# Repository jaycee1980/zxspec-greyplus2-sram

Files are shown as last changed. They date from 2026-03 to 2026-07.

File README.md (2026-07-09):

# zxspec-greyplus2-sram
A replacement RAM module for a ZX Spectrum +2 (Grey) machine to replace 8x4164 chips

# What's it for ?
The grey +2 uses 4164 (64Kx1) DRAM as its system memory... there are two banks of it, one as "Contended" RAM, one as "Uncontended" RAM. This is similar in principle to the 4116 (16x1) DRAM and 4532 (32Kx1) DRAM in the original 48K spectrum. These chips can and do fail, and procuring replacements is getting more and more difficult.

For 48K spectrums, there are Lower and Upper RAM Replacement boards utilising modern 5V SRAM as a replacement. I couldn't find an equivalent solution for a grey +2 though.

So here we are! :)
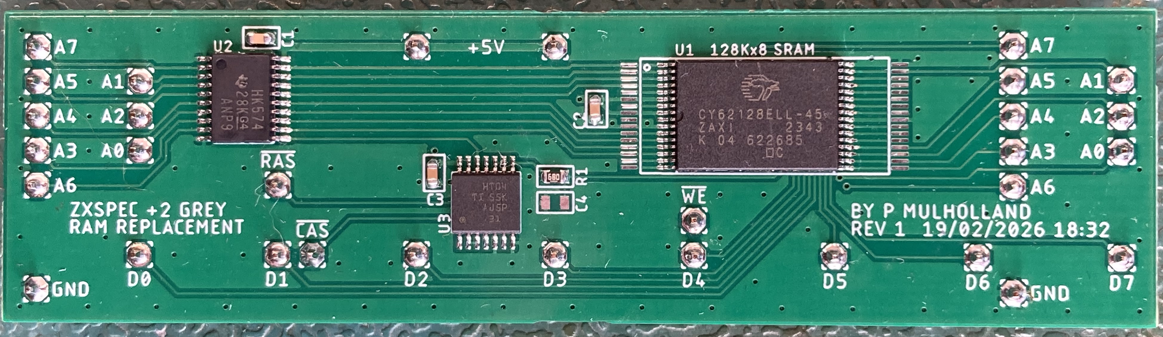
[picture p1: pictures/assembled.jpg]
image of assembled board


# Building it
The gerber.zip file in this repository contains Gerber files needed by a PCB manufacturer to make the board. I personally use [JLCPCB](https://jlcpcb.com) but any PCB manufacturer should be able to produce it.

The [BOM file](/bom.txt) contains the parts needed to make the board. Please note that I have only personally used the Cypress CY62128ELL-45ZAXI memory at the moment, but the other SRAM listed there should also work. You *might* need to install C4 in some cases. My personal grey +2 worked just fine without it.

Also be aware that on the back of the PCB there is a jumper pad. This should be bridged such that the A pad is connected to the middle pad. You can use a solder blob, a short length of wire, or a 0 ohm resistor for this.

# License

If you wish to sell this please contact me at github@dark-matter.me.uk - I will usually grant permission provided they are sold for reasonable cost, and my name is not removed from the design.

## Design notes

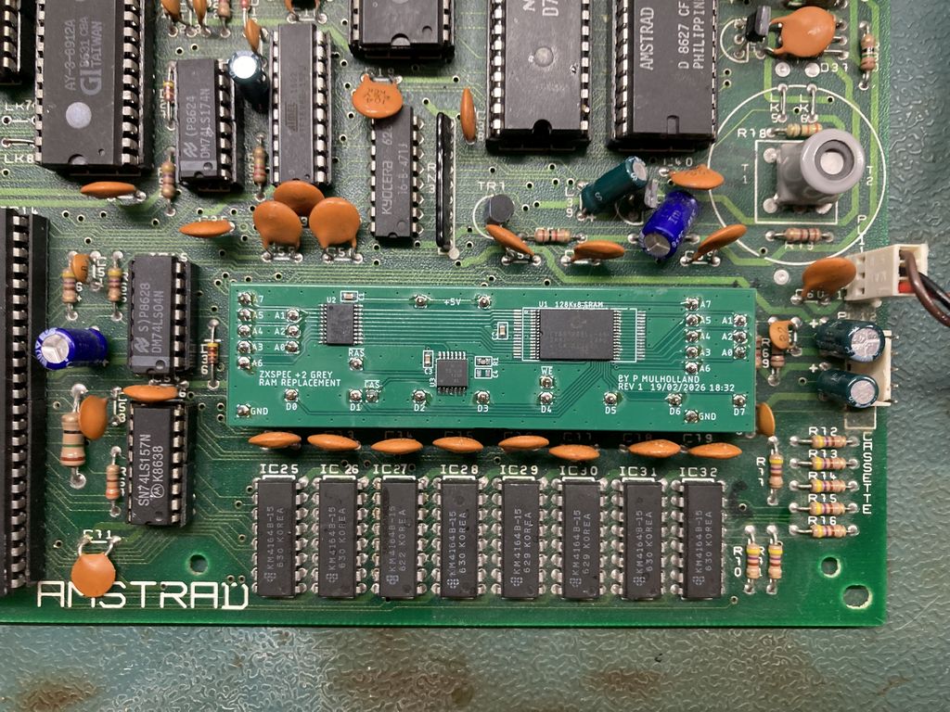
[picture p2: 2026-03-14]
pictures/fitted_th.jpg

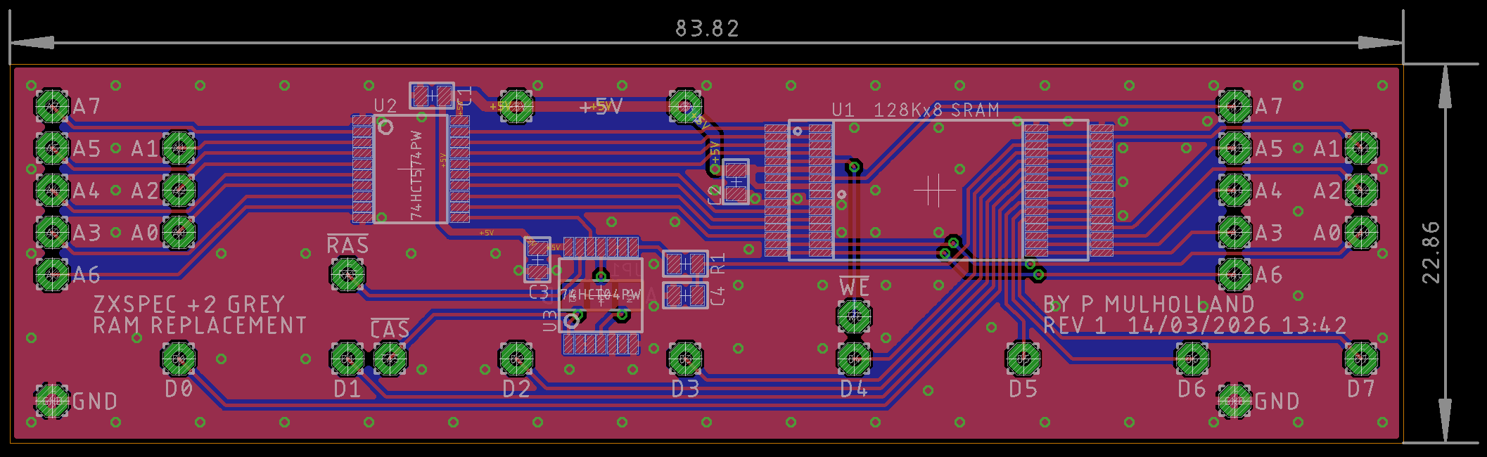
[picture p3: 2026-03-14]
pictures/board.png

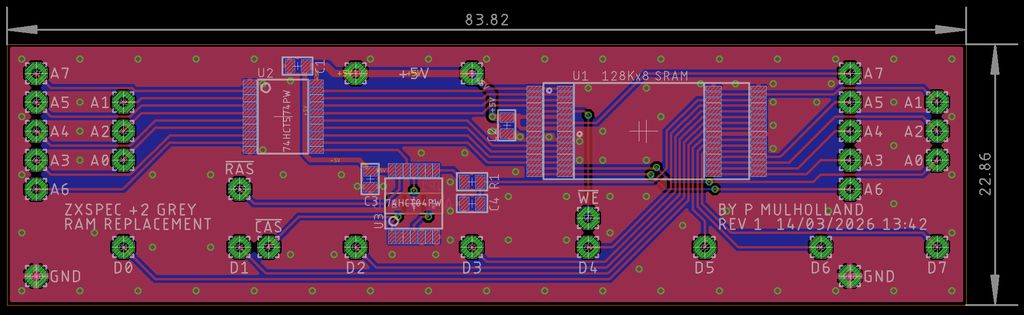
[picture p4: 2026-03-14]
pictures/board_th.jpg

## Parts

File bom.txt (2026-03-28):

Main components:
C1, C3		100nF 50V ceramic capacitor, SMD 0603		Digikey 399-C0603C104K5RACTUCT-ND, Mouser 603-CC0603MR9BB104, LCSC C14663
C2			1uF 16V ceramic capacitor, SMD 0603			Digikey 399-C0603C105K4RACTUCT-ND, Mouser 80-C0603C105K8R, LCSC C15849
R1			68 ohm 1% resistor, SMD 0603				Digikey 311-68.0HRCT-ND, Mouser 603-RC0603FR-1368RL, LCSC C27592
U2			74HCT574, TSSOP 20 package					Digikey 296-17126-1-ND, Mouser 595-CD74HCT574PWR, LCSC C2652839
U3			74HCT04, TSSOP 14 package					Digikey 296-17123-1-ND, Mouser 595-CD74HCT04PWR, LCSC C131695

Optional:
C4			100pF 1% C0G ceramic capacitor, SMD 0603	Digikey 399-C0603C101J5GACTUCT-ND, Mouser 603-CC402FRNPO9BN101, LCSC C14858

Suitable SRAM:
Cypress CY62128ELL-45ZAXI		LCSC C2950636
Infineon CY62128ELL-45ZXI		Digikey 448-CY62128ELL-45ZXITCT-ND, Mouser 727-CY62128ELL45ZXI
ISSI IS62C1024AL-35TLI			Digikey 706-1309-1-ND, Mouser 870IS62C1024AL35TLI
Renesas R1LP0108ESA-5SI#S1		Digikey R1LP0108ESA-5SI#S1CT-ND, Mouser 968-R1LP0108ESA5SIS1
Renesas R1LP0108ESA-5SI#B1		Mouser 968-R1LP0108ESA5SIB1
Alliance AS6C1008-55TIN			Mouser 913-AS6C1008-55TIN

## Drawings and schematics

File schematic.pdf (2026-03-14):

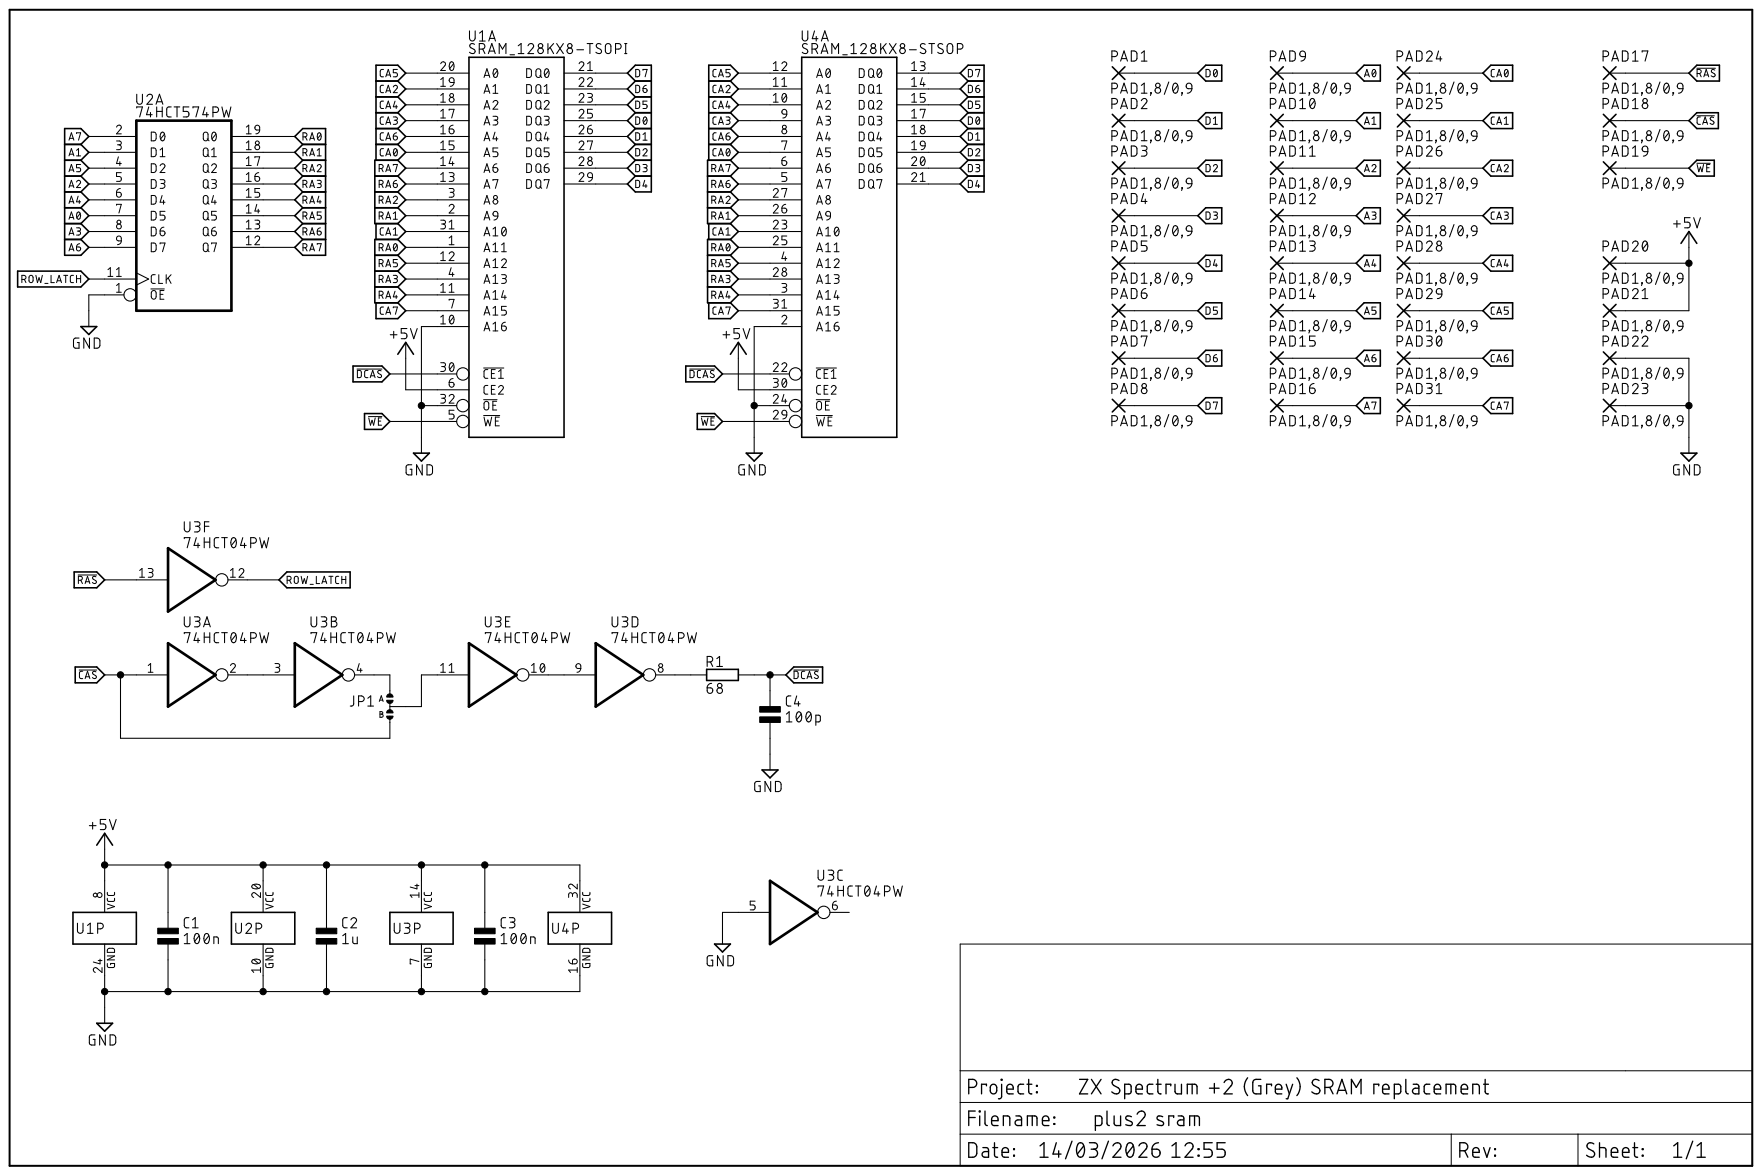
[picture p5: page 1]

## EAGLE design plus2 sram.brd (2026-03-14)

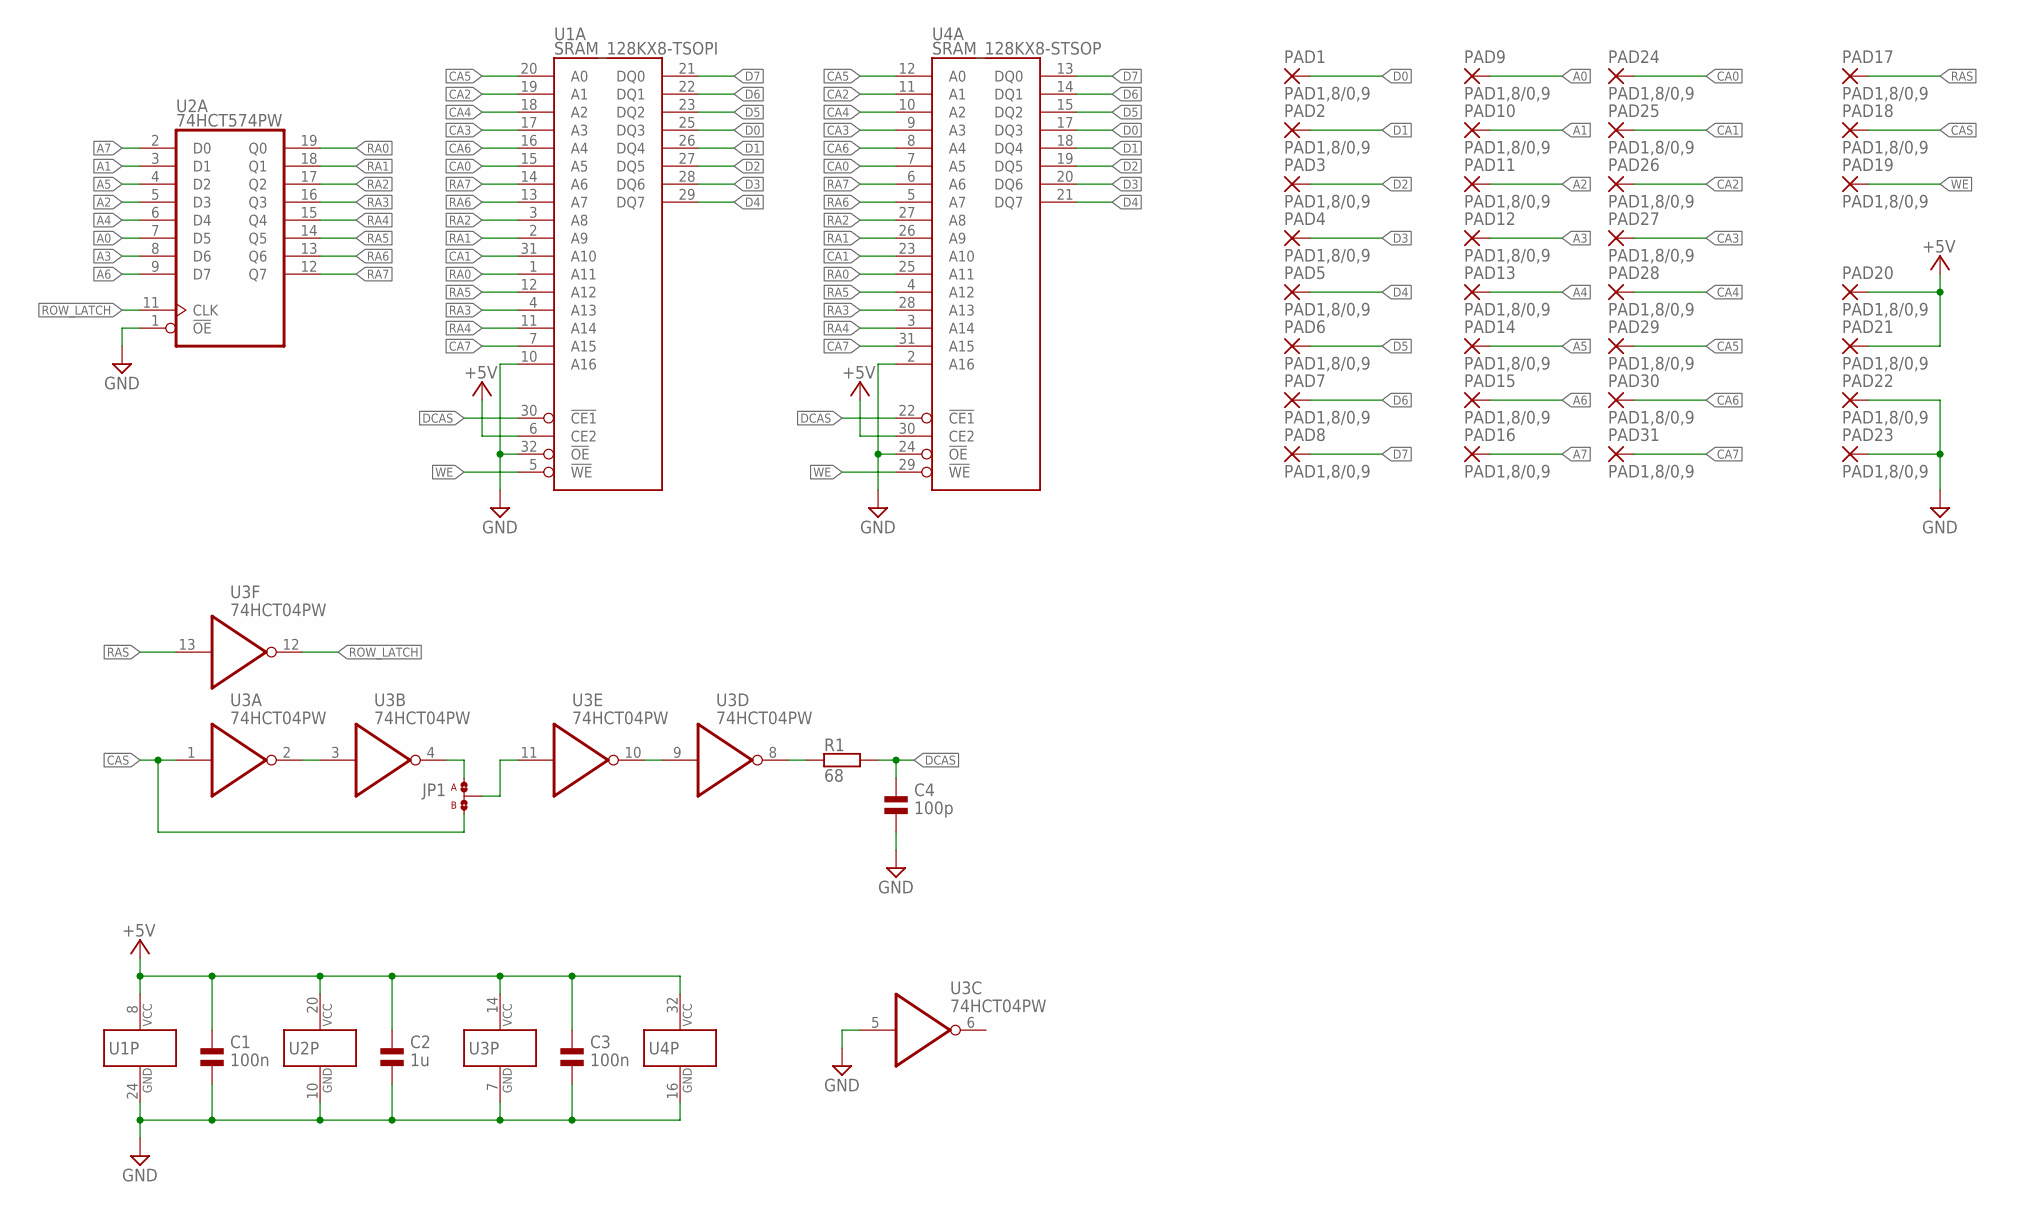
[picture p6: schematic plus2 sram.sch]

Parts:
C1, C3: 100n; 0603
C2: 1u; 0603
C4: 100p; 0603
JP1: JMP-SMD-3W0805; SJ-3P-0805
PAD1, PAD2, PAD3, PAD4, PAD5, PAD6, PAD7, PAD8, PAD9, PAD10, PAD11, PAD12, PAD13, PAD14, PAD15, PAD16, PAD17, PAD18, PAD19, PAD20, PAD21, PAD22, PAD23, PAD24, PAD25, PAD26, PAD27, PAD28, PAD29, PAD30, PAD31: PAD1,8/0,9; 1,8/0,9
R1: 68; 0603
U1: SRAM_128KX8-TSOPI; TSOP-I-32
U2: 74HCT574PW; TSSOP20
U3: 74HCT04PW; TSSOP14
U4: SRAM_128KX8-STSOP; STSOP-32

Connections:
!CAS: JP1.B, PAD18.1, U3.1 (I)
!DCAS: C4.1, R1.2, U1.30 (!CE1), U4.22 (!CE1)
!RAS: PAD17.1, U3.13 (I)
!WE: PAD19.1, U1.5 (!WE), U4.29 (!WE)
+5V: C1.1, C2.1, C3.1, PAD20.1, PAD21.1, U1.6 (CE2), U1.8 (VCC), U2.20 (VCC), U3.14 (VCC), U4.30 (CE2), U4.32 (VCC)
A0: PAD9.1, U2.7 (D5)
A1: PAD10.1, U2.3 (D1)
A2: PAD11.1, U2.5 (D3)
A3: PAD12.1, U2.8 (D6)
A4: PAD13.1, U2.6 (D4)
A5: PAD14.1, U2.4 (D2)
A6: PAD15.1, U2.9 (D7)
A7: PAD16.1, U2.2 (D0)
CA0: PAD24.1, U1.15 (A5), U4.7 (A5)
CA1: PAD25.1, U1.31 (A10), U4.23 (A10)
CA2: PAD26.1, U1.19 (A1), U4.11 (A1)
CA3: PAD27.1, U1.17 (A3), U4.9 (A3)
CA4: PAD28.1, U1.18 (A2), U4.10 (A2)
CA5: PAD29.1, U1.20 (A0), U4.12 (A0)
CA6: PAD30.1, U1.16 (A4), U4.8 (A4)
CA7: PAD31.1, U1.7 (A15), U4.31 (A15)
D0: PAD1.1, U1.25 (DQ3), U4.17 (DQ3)
D1: PAD2.1, U1.26 (DQ4), U4.18 (DQ4)
D2: PAD3.1, U1.27 (DQ5), U4.19 (DQ5)
D3: PAD4.1, U1.28 (DQ6), U4.20 (DQ6)
D4: PAD5.1, U1.29 (DQ7), U4.21 (DQ7)
D5: PAD6.1, U1.23 (DQ2), U4.15 (DQ2)
D6: PAD7.1, U1.22 (DQ1), U4.14 (DQ1)
D7: PAD8.1, U1.21 (DQ0), U4.13 (DQ0)
GND: C1.2, C2.2, C3.2, C4.2, PAD22.1, PAD23.1, U1.10 (A16), U1.24 (GND), U1.32 (!OE), U2.1 (!OE), U2.10 (GND), U3.5 (I), U3.7 (GND), U4.2 (A16), U4.16 (GND), U4.24 (!OE)
unnamed: R1.1, U3.8 (O)
unnamed: U3.2 (O), U3.3 (I)
unnamed: JP1.COM, U3.11 (I)
unnamed: U3.9 (I), U3.10 (O)
unnamed: JP1.A, U3.4 (O)
RA0: U1.1 (A11), U2.19 (Q0), U4.25 (A11)
RA1: U1.2 (A9), U2.18 (Q1), U4.26 (A9)
RA2: U1.3 (A8), U2.17 (Q2), U4.27 (A8)
RA3: U1.4 (A13), U2.16 (Q3), U4.28 (A13)
RA4: U1.11 (A14), U2.15 (Q4), U4.3 (A14)
RA5: U1.12 (A12), U2.14 (Q5), U4.4 (A12)
RA6: U1.13 (A7), U2.13 (Q6), U4.5 (A7)
RA7: U1.14 (A6), U2.12 (Q7), U4.6 (A6)
ROW_LATCH: U2.11 (CLK), U3.12 (O)

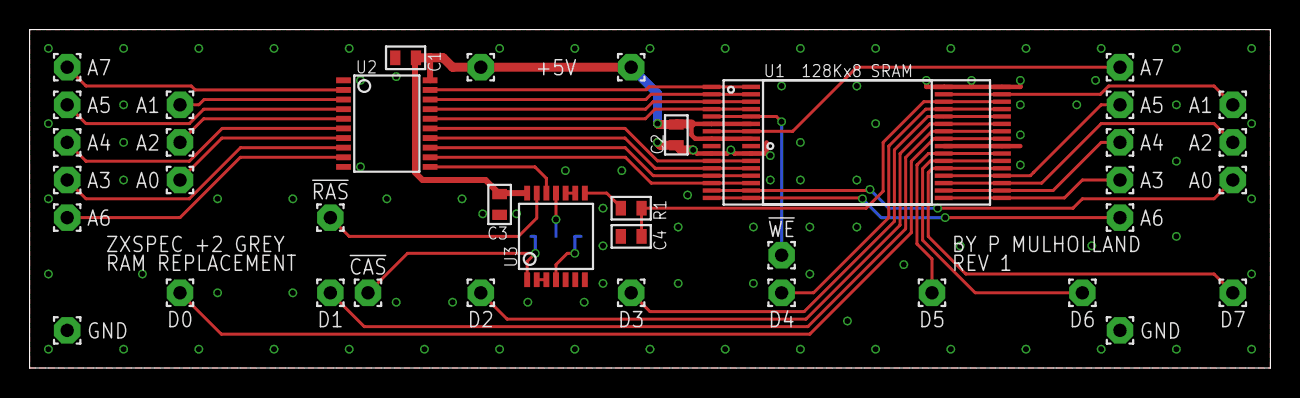
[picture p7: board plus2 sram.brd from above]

Board: 2 copper layers, 83.8 x 22.9 mm, 41 parts (1 on the bottom side), 44 nets.
